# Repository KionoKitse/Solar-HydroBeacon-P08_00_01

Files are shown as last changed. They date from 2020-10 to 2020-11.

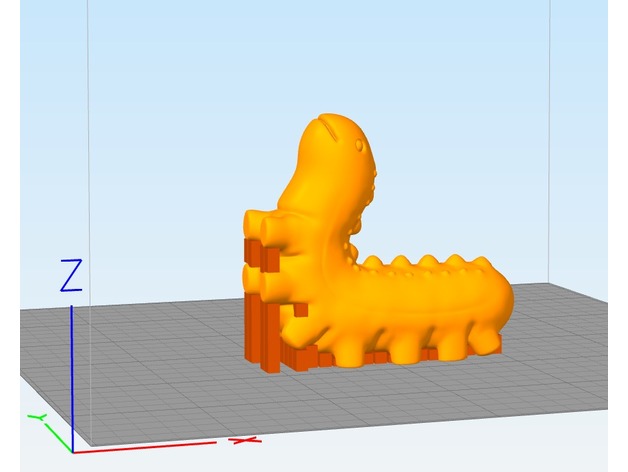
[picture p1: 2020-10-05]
P08_01_00 Thingverse CAD/cute_caterpillar/images/ec77e9b82f7213b1b38d7afa50246b58_preview_featured.jpg

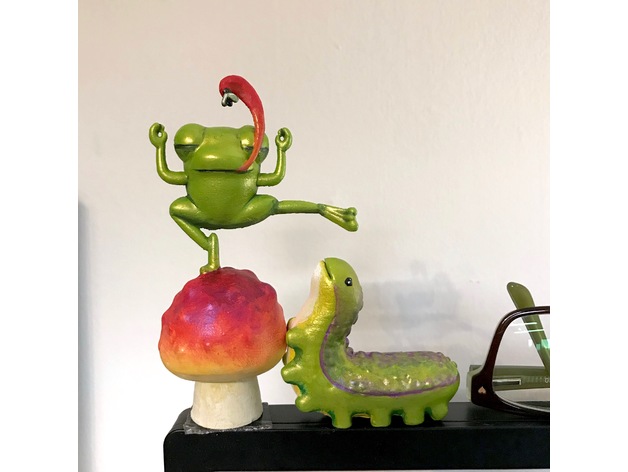
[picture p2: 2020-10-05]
P08_01_00 Thingverse CAD/cute_caterpillar/images/cc7cc02f7ef95b9d1e0543dbf46717a2_preview_featured.jpeg

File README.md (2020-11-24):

### Description  
P08_01_00 Solar HydroBeacon
A solar powered soil moisture sensor project.
 * Solar powered
 * LED indicates soil moisture low or acceptable
 * Low to no maintenance
 * Capacitor as power source
 * Analog components 
 * Low cost
 * Interesting and elegant design
 * Small size
### Notes to user
 * Project documented at https://kionokitse.wordpress.com/solar-hydrobeacon/
 * In development
### What's next
 * Determine typical soil moisture levels
 * Determine trimpot value that would be the best for the typical soil moistures
 * Find voltage supervisors that would work
 * Order solar panels
 * Test led drivers
### Notebook
 * Online circuit simulator [link](http://falstad.com/circuit/)
 * Case design options
	* Case option: [Neko Submarine](https://www.thingiverse.com/thing:3081218) 
	* Case option: [cute caterpillar](https://www.thingiverse.com/thing:3598906)
	* Case option: [Pom Pom Purin keychain](https://www.thingiverse.com/thing:1188272)
 * Voltage detector 
	* Trimpot should be about 50% less than sensor resistance
	* Voltage divider total resistance should be high to limit current flow
	* On build I need to re-tune the circuit
	* Added a 500Ohm resistor to cut down on the wasted current to turn on the green led
 * Solar LED driver
	* Good intro to the solar LED driver featuring the YX8018 IC [Link](https://ez.analog.com/adieducation/university-program/b/blogs/posts/hacking-an-led-solar-garden-light)
	* Solar powered soil moisture sensor project [Link](https://learn.sparkfun.com/tutorials/soil-moisture-sensing-by-hacking-a-solar-light/all)
	* When the CE pin on ANA608 is high the LED will turn ON
	* When the CE pin on ANA608 is low the LED will trun OFF
 * Blink circuit [Link](http://tinyurl.com/y29udzjd)
	* Need to tune the circuit for low voltage operation
	* Increasing the green capacitor size will increase the time that the green capacitor is on
	* Reducing the resistance before the red LED will increase the red led brightness
	* Latest progress on this [Link](http://tinyurl.com/y2kkg7hm)
 * Simulate Solar engines
	* [The Zener-based solar engine](http://solarbotics.net/library/circuits/se_t1_zener.html) [Simulation](https://tinyurl.com/y29gntqv) (not working yet)
	* [FLED-based solar engines](http://solarbotics.net/library/circuits/se_t1_fled.html) [Simulation](https://tinyurl.com/y26xv6wr) (not working yet)
 * Simple blink circuit [Link](https://electronics.stackexchange.com/questions/356947/intuitive-and-iterative-approach-to-understanding-of-blinking-led-circuit)
 * DC-DC converter based on solar LED light
	* Dollar Store Garden Lights As ATtiny Power Supplies [Link](https://hackaday.io/project/164682-a-cheap-and-dangerous-garden-light-boost-converter/details)
		* Interesting use of an ATtiny85V to directly control YX8051 by manipulating the solar voltage input. A cap will hold off the 10V voltage spikes.
	* DC-DC converter based on solar LED light [Link](https://skootsone.yolasite.com/solar-led-msp430.php)
		* Seems to be a more stable version but requires a lot of additional components
	* Running a transmitter and a ATtiny85 off a solar led driver [Link](https://web.archive.org/web/20170119175434/http://www.dolenle.com/proj4.html)
		*No images and it is long but I think it will be worth a replica
	* Using a YX805A to get a stable 5V power output for ATtiny85 or others [Link](https://dzrmo.wordpress.com/2017/01/02/garden-light-redux-aka-joule-thief-p-1/)
	* XY8018 boost regulator with trimpot control [Link](http://www.radioradar.net/radiofan/lighting/yx8018.html) [Translated](https://translate.google.com/translate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)
 * Resources
	* Circuit diagrams making use of LED divers [Link](https://skootsone.yolasite.com/solar-led.php)
		* Interesting design for a blinker I might test
		* Interesting component breakdown of what is inside of a solar led driver

 * Website with some solar circuits maybe useful later [Link](https://www.electroschematics.com/category/solar-projects/)
	
### Progress log 
 * 2020-09-19 Got some garden lights from the store to test these led drivers
 * 2020-09-19 Testing the led drivers. It doesn't look like I can drive an ATtiny85 directly off the boosted voltage
 * 2020-09-19 Fried both led divers. Not sure how but maybe too much heat from the soldering iron
 * 2020-09-21 Officially start project and create Git repository
 * 2020-09-21 Looking for possible designs
 * 2020-09-22 Looking for a analog method to compare voltages
 * 2020-09-23 Created a circuit that turns on a green LED if the resistance is low [link](http://tinyurl.com/y6nuq4zt) 
 * 2020-09-23 Created a circuit design that turns on a red led if the resistance is high [link](http://tinyurl.com/yysaw5k8) 
 * 2020-09-23 Attempted circuit design with both options (not working) [link](http://tinyurl.com/y6hwgj95)
 * 2020-09-24 Looking into logic diagrams
 * 2020-09-24 Got 50 more led divers in the mail
 * 2020-09-25 Created a working simulated circuit at 5v that will turn a red led on if resistance is high or a green led if resistance is low [link](http://tinyurl.com/yyqalqkw)
 * 2020-09-30 Modifying the caterpillar STL for the project
 * 2020-10-01 Searching for a voltage supervisor IC to control when to activate the circuit
 * 2020-10-05 Fined turning the voltage detector circuit for 2V [link](http://tinyurl.com/yxfx4we7)
 * 2020-10-05 Testing sample miller style circuit [Link](http://tinyurl.com/y38uw3cg)
 * 2020-10-05 Improving voltage flow [Link] (http://tinyurl.com/yymy2248)
 * 2020-10-05 Circuit with voltage comparator and solar engine (not really working) [Link](http://tinyurl.com/y5qvovyz)
 * 2020-10-05 Current progress with circuit design [Link](http://tinyurl.com/yxzwtum5)
 * 2020-10-08 Experimenting with the ANA608 solar LED driver
 * 2020-10-08 ANA608 seems to work but I should explore expanded usage scenarios 
 * 2020-10-10 Tested running ATtiny85 directly off ANA608 no luck
 * 2020-10-13 Simple blink circuit from [here](https://www.build-electronic-circuits.com/blinking-led-circuit/)[Link](http://tinyurl.com/y29udzjd)
 * 2020-10-14 Doing research on solar led divers and modifying them for constant boosted DC voltage
 * 2020-10-14 Buy some test parts from mouser
 * 2020-10-15 building test circuits no luck I think mc4742 is an invalid part number
 * 2020-10-17 Tested running ATtiny85 directly off ANA608 no luck
 * 2020-10-26 Mouser parts arrived (2 weeks delivery) 
 * 2020-10-30 Testing [this](https://dzrmo.wordpress.com/2017/01/02/garden-light-redux-aka-joule-thief-p-1/) circuit with the new parts. Seems to work
 * 2020-11-03 Solar power circuit seems to work best with a Schottky diode instead of rectifier diode
 * 2020-11-03 Rectifier diode drops the voltage too low to run green LEDs
 * 2020-11-08 Testing solar power circuit to optimize setup
 * 2020-11-08 Getting stable power from ANA608 stays at about 3.3V when ATtiny85 is doing nothing
 * 2020-11-08 Write initial main AVR sketch
 * 2020-11-08 Created breadboard prototype with moisture sensor, trimpot reference, Green/Red LEDs and microcontroller results successful
 * 2020-11-09 Got the ANA608 with the LDR to work and power the ATtiny85
 * 2020-11-09 LDR helps a lot to delay the start time
 * 2020-11-09 Microcontroller does not reboot when light turned back on only if remove battery
 * 2020-11-09 Smallest capacitor that seems to work okay is 47uF
 * 2020-11-10 Checking space in caterpillar model for battery
 * 2020-11-10 Both batteries seem to fit
 * 2020-11-10 Modifying CAD to make room for LDR
 * 2020-11-16 Needed to use blender to modify CAD
 * 2020-11-16 Printing caterpillar
 * 2020-11-17 Testing new solar panels results are disappointing needs review

### Next Blog Post

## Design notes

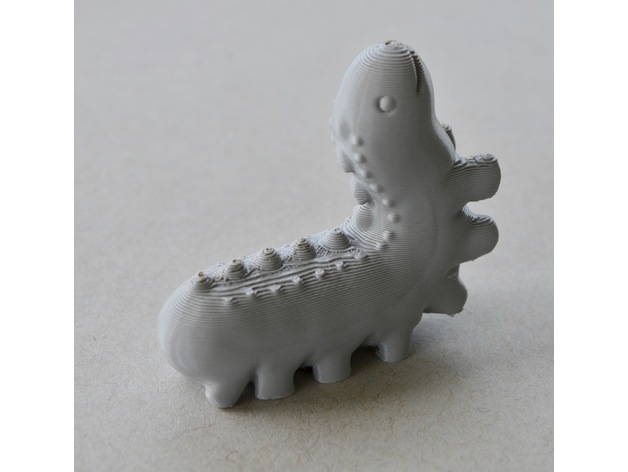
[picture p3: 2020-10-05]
P08_01_00 Thingverse CAD/cute_caterpillar/images/f7e0081296a51953a6b59a4de3f70e1f_preview_featured.jpeg

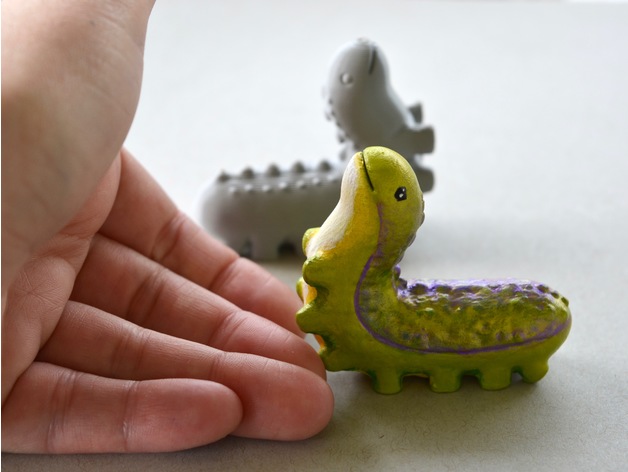
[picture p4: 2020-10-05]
P08_01_00 Thingverse CAD/cute_caterpillar/images/7b63a44b5848a8bd771d972aaded3b9b_preview_featured.jpeg

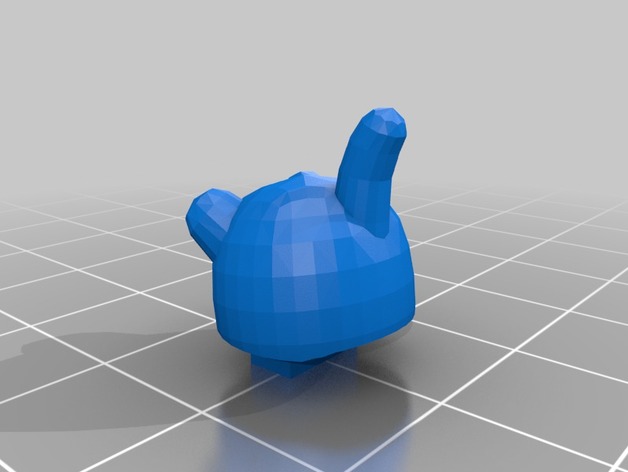
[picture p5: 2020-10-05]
P08_01_00 Thingverse CAD/Neko_Submarine/images/8ecf5cf895d3a4468f53bc3277c36801_preview_featured.jpg

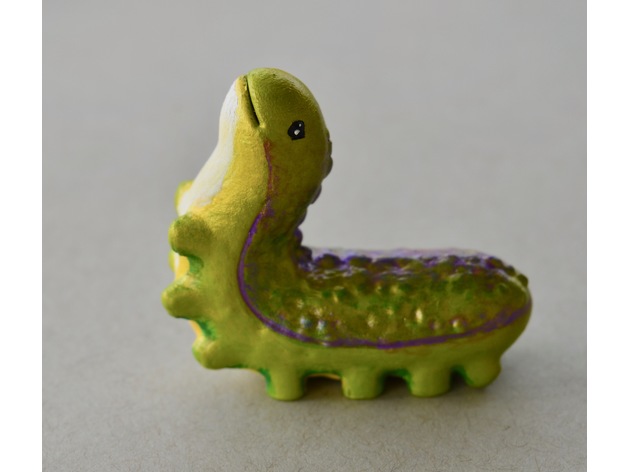
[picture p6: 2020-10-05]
P08_01_00 Thingverse CAD/cute_caterpillar/images/7d05ed157128572da64a1c4cd77189d9_preview_featured.jpeg

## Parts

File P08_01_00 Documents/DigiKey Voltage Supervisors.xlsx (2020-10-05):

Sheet: Filtered
Mfr Part # | Price | Type | Output | Reset | Reset Timeout | Voltage - Threshold | V-On | uA | Notes
BU4315FVE-TR | 0.34206 | Simple Reset/Power-On Reset | Push-Pull, Totem Pole | Active Low | Adjustable/Selectable | 1.5V | 0.7 | 0.55
RT9819C-13GU3 | 0.62 | Simple Reset/Power-On Reset | Push-Pull, Totem Pole | Active Low | 143ms Minimum | 1.3V | 0 | 0 | Invalid
BD5215G-2MTR | 0.67 | Voltage Detector | Open Drain or Open Collector | Active Low | - | 1.5V | 0.8 | 0.27
BU4813G-TR | 0.67 | Simple Reset/Power-On Reset | Open Drain or Open Collector | Active High/Active Low | - | 1.3V | 0.7 | 0.55
XC6120N152NR-G | 0.7 | Voltage Detector | Open Drain or Open Collector | Active Low | - | 1.5V
RN5VD15AA-TR-FE | 0.73 | Voltage Detector | Open Drain or Open Collector | - | - | 1.5V
BU4213G-TR | 0.74 | Simple Reset/Power-On Reset | Open Drain or Open Collector | Active Low | Adjustable/Selectable | 1.3V | 0.7 | 0.55
BU4215G-TR | 0.74 | Simple Reset/Power-On Reset | Open Drain or Open Collector | Active Low | Adjustable/Selectable | 1.5V | 0.7 | 0.55
NCP302LSN15T1G | 0.8 | Simple Reset/Power-On Reset | Push-Pull, Totem Pole | Active Low | Adjustable/Selectable | 1.5V | 0.65 | 0.2
NCP303LSN13T1G | 0.8 | Simple Reset/Power-On Reset | Open Drain or Open Collector | Active Low | Adjustable/Selectable | 1.3V | 0.65 | 0.2
NCP303LSN14T1G | 0.8 | Simple Reset/Power-On Reset | Open Drain or Open Collector | Active Low | Adjustable/Selectable | 1.4V | 0.65 | 0.2
NCP303LSN15T1G | 0.8 | Simple Reset/Power-On Reset | Open Drain or Open Collector | Active Low | Adjustable/Selectable | 1.5V | 0.65 | 0.2
NCP305LSQ15T1G | 0.8 | Simple Reset/Power-On Reset | Open Drain or Open Collector | Active Low | - | 1.5V | 0.65 | 0.2
TC54VC1402ECB713 | 0.8 | Simple Reset/Power-On Reset | Push-Pull, Totem Pole | Active Low | - | 1.4V
TC54VN1402ECB713 | 0.8 | Simple Reset/Power-On Reset | Open Drain or Open Collector | Active Low | - | 1.4V
XC61CN1502MR-G | 0.89 | Voltage Detector | Open Drain or Open Collector | - | - | 1.5V
R3112N131A-TR-FE | 0.92 | Voltage Detector | Open Drain or Open Collector | Active Low | - | 1.3V | 0.7 | 0.5
R3112Q131A-TR-FE | 0.92 | Voltage Detector | Open Drain or Open Collector | Active Low | - | 1.3V
BU4213FVE-TR | 0.95 | Simple Reset/Power-On Reset | Open Drain or Open Collector | Active Low | Adjustable/Selectable | 1.3V | 0.7 | 0.55
R3112D151A-TR-FE | 0.97 | Voltage Detector | Open Drain or Open Collector | Active Low | - | 1.5V | 0.65 | 0.2
R3116Q151C-TR-FE | 1.09 | Voltage Detector | Push-Pull, Totem Pole | Active Low | 85ms Minimum | 1.5V
S-1000C15-I4T1U | 1.14 | Voltage Detector | Push-Pull, Totem Pole | Active Low | - | 1.5V
S-1000N15-I4T1U | 1.14 | Voltage Detector | Open Drain or Open Collector | Active Low | - | 1.5V
S-1000N15-M5T1U | 1.14 | Voltage Detector | Open Drain or Open Collector | Active Low | - | 1.5V
S-80814CLNB-B7ST2U | 1.14 | Voltage Detector | Push-Pull, Totem Pole | Active Low | - | 1.4V
S-80814CLPF-B7STFU | 1.14 | Voltage Detector | Push-Pull, Totem Pole | Active Low | - | 1.4V
S-80814CNNB-B9ST2U | 1.14 | Voltage Detector | Open Drain or Open Collector | Active Low | - | 1.4V
S-80815CLNB-B6AT2U | 1.14 | Voltage Detector | Push-Pull, Totem Pole | Active Low | - | 1.5V
S-80815CLPF-B6ATFU | 1.14 | Voltage Detector | Push-Pull, Totem Pole | Active Low | - | 1.5V
S-80815CNMC-B8AT2U | 1.14 | Voltage Detector | Open Drain or Open Collector | Active Low | - | 1.5V
S-80815CNNB-B8AT2U | 1.14 | Voltage Detector | Open Drain or Open Collector | Active Low | - | 1.5V
R3116K151A-TR | 1.15 | Voltage Detector | Open Drain or Open Collector | Active Low | 85ms Minimum | 1.5V
R3116K151C-TR | 1.15 | Voltage Detector | Push-Pull, Totem Pole | Active Low | 85ms Minimum | 1.5V
S-1009C13I-N4T1U | 1.18 | Voltage Detector | Push-Pull, Totem Pole | Active Low | - | 1.3V
S-1009C14I-M5T1U | 1.18 | Voltage Detector | Push-Pull, Totem Pole | Active Low | - | 1.4V
S-1009C15I-I4T1U | 1.18 | Voltage Detector | Push-Pull, Totem Pole | Active Low | - | 1.5V
S-1009N13I-I4T1U | 1.18 | Voltage Detector | Open Drain or Open Collector | Active Low | - | 1.3V
S-1009N13I-M5T1U | 1.18 | Voltage Detector | Open Drain or Open Collector | Active Low | - | 1.3V
S-1009N14I-M5T1U | 1.18 | Voltage Detector | Open Drain or Open Collector | Active Low | - | 1.4V
S-1009N15I-I4T1U | 1.18 | Voltage Detector | Open Drain or Open Collector | Active Low | - | 1.5V
S-1009N15I-M5T1U | 1.18 | Voltage Detector | Open Drain or Open Collector | Active Low | - | 1.5V
S-1009N15I-N4T1U | 1.18 | Voltage Detector | Open Drain or Open Collector | Active Low | - | 1.5V
S-80913CNMC-G8HT2U | 1.18 | Voltage Detector | Open Drain or Open Collector | Active Low | 2.7ms Minimum | 1.3V
S-80914CLMC-G6JT2U | 1.18 | Voltage Detector | Push-Pull, Totem Pole | Active Low | 2.7ms Minimum | 1.4V
S-80914CLPF-G6JTFU | 1.18 | Voltage Detector | Push-Pull, Totem Pole | Active Low | 2.7ms Minimum | 1.4V
S-80914CNPF-G8JTFU | 1.18 | Voltage Detector | Open Drain or Open Collector | Active Low | 2.7ms Minimum | 1.4V
S-80915CLMC-G6KT2U | 1.18 | Voltage Detector | Push-Pull, Totem Pole | Active Low | 18ms Minimum | 1.5V
S-80915CLNB-G6KT2U | 1.18 | Voltage Detector | Push-Pull, Totem Pole | Active Low | 18ms Minimum | 1.5V
S-80915CLPF-G6KTFU | 1.18 | Voltage Detector | Push-Pull, Totem Pole | Active Low | 18ms Minimum | 1.5V
S-80915CNMC-G8KT2U | 1.18 | Voltage Detector | Open Drain or Open Collector | Active Low | 20ms Minimum | 1.5V
S-80915CNPF-G8KTFU | 1.18 | Voltage Detector | Open Drain or Open Collector | Active Low | 20ms Minimum | 1.5V
S-1002CA15I-M5T1U | 1.3 | Voltage Detector | Push-Pull, Totem Pole | Active Low | - | 1.5V
R3118N151A-TR-FE | 1.32 | Voltage Detector | Open Drain or Open Collector | Active Low | 70ms Minimum | 1.5V
R3118N151C-TR-FE | 1.32 | Voltage Detector | Push-Pull, Totem Pole | Active Low | 70ms Minimum | 1.5V
S-1004CA14I-I6T1U | 1.35 | Voltage Detector | Push-Pull, Totem Pole | Active Low | - | 1.4V
S-1004CA15I-M5T1U | 1.35 | Voltage Detector | Push-Pull, Totem Pole | Active Low | - | 1.5V
S-1004NB15I-M5T1U | 1.35 | Voltage Detector | Open Drain or Open Collector | Active Low | - | 1.5V
TPS3803G15DCKR | 1.35 | Simple Reset/Power-On Reset | Open Drain or Open Collector | Active Low | 5µs Typical Propagation Delay | 1.4V
TPS3808G15DBVR | 2.38 | Simple Reset/Power-On Reset | Open Drain or Open Collector | Active Low | Adjustable/Selectable | 1.4V
TPS389015DSER | 2.42 | Simple Reset/Power-On Reset | Open Drain or Open Collector | Active Low | - | 1.5V
TPS3808G15DBVT | 2.44 | Simple Reset/Power-On Reset | Open Drain or Open Collector | Active Low | Adjustable/Selectable | 1.4V
TPS389015DSET | 2.48 | Simple Reset/Power-On Reset | Open Drain or Open Collector | Active Low | - | 1.5V
TPS3808G15DRVT | 2.54 | Simple Reset/Power-On Reset | Open Drain or Open Collector | Active Low | Adjustable/Selectable | 1.4V

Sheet: Full Results
Voltage - Threshold | Mfr Part # | Price | Type | Output | Reset | Reset Timeout
1.5V | BU4315FVE-TR | 0.34206 | Simple Reset/Power-On Reset | Push-Pull, Totem Pole | Active Low | Adjustable/Selectable
1.3V | RT9819C-13GU3 | 0.62 | Simple Reset/Power-On Reset | Push-Pull, Totem Pole | Active Low | 143ms Minimum
1.5V | BD5215G-2MTR | 0.67 | Voltage Detector | Open Drain or Open Collector | Active Low | -
1.2V | BD5212G-2MTR | 0.67 | Voltage Detector | Open Drain or Open Collector | Active Low | -
1V | BD5210G-2MTR | 0.67 | Voltage Detector | Open Drain or Open Collector | Active Low | -
1V | BU4810G-TR | 0.67 | Simple Reset/Power-On Reset | Open Drain or Open Collector | Active High/Active Low | -
1.3V | BU4813G-TR | 0.67 | Simple Reset/Power-On Reset | Open Drain or Open Collector | Active High/Active Low | -
0.9V | BU4809G-TR | 0.67 | Simple Reset/Power-On Reset | Open Drain or Open Collector | Active High/Active Low | -
1.5V | XC6120N152NR-G | 0.7 | Voltage Detector | Open Drain or Open Collector | Active Low | -
0.9V | NCP301LSN09T1G | 0.71 | Simple Reset/Power-On Reset | Open Drain or Open Collector | Active Low | -
0.9V | NCP303LSN09T2G | 0.71 | Simple Reset/Power-On Reset | Open Drain or Open Collector | Active Low | Adjustable/Selectable
1.5V | RN5VD15AA-TR-FE | 0.73 | Voltage Detector | Open Drain or Open Collector | - | -
0.9V | RN5VD09AA-TR-FE | 0.73 | Voltage Detector | Open Drain or Open Collector | - | -
1.5V | BU4215G-TR | 0.74 | Simple Reset/Power-On Reset | Open Drain or Open Collector | Active Low | Adjustable/Selectable
0.9V | BU4209G-TR | 0.74 | Simple Reset/Power-On Reset | Open Drain or Open Collector | Active Low | Adjustable/Selectable
1V | BU4210G-TR | 0.74 | Simple Reset/Power-On Reset | Open Drain or Open Collector | Active Low | Adjustable/Selectable
1.3V | BU4213G-TR | 0.74 | Simple Reset/Power-On Reset | Open Drain or Open Collector | Active Low | Adjustable/Selectable
1.2V | BU4212G-TR | 0.74 | Simple Reset/Power-On Reset | Open Drain or Open Collector | Active Low | Adjustable/Selectable
1.1V | BU4211G-TR | 0.74 | Simple Reset/Power-On Reset | Open Drain or Open Collector | Active Low | Adjustable/Selectable
1.1V | XC6120C112HR-G | 0.79 | Voltage Detector | Push-Pull, Totem Pole | Active Low | -
1V | NCP303LSN10T1G | 0.8 | Simple Reset/Power-On Reset | Open Drain or Open Collector | Active Low | Adjustable/Selectable
1.1V | NCP303LSN11T1G | 0.8 | Simple Reset/Power-On Reset | Open Drain or Open Collector | Active Low | Adjustable/Selectable
1.5V | NCP302LSN15T1G | 0.8 | Simple Reset/Power-On Reset | Push-Pull, Totem Pole | Active Low | Adjustable/Selectable
0.9V | NCP305LSQ09T1G | 0.8 | Simple Reset/Power-On Reset | Push-Pull, Totem Pole | Active Low | -
1.3V | NCP303LSN13T1G | 0.8 | Simple Reset/Power-On Reset | Open Drain or Open Collector | Active Low | Adjustable/Selectable
1.4V | NCP303LSN14T1G | 0.8 | Simple Reset/Power-On Reset | Open Drain or Open Collector | Active Low | Adjustable/Selectable
0.9V | NCP302LSN09T1G | 0.8 | Simple Reset/Power-On Reset | Push-Pull, Totem Pole | Active Low | Adjustable/Selectable
0.9V | NCP302HSN09T1G | 0.8 | Simple Reset/Power-On Reset | Push-Pull, Totem Pole | Active High | Adjustable/Selectable
1.2V | NCP301LSN12T1G | 0.8 | Simple Reset/Power-On Reset | Open Drain or Open Collector | Active Low | -
0.9V | NCP301HSN09T1G | 0.8 | Simple Reset/Power-On Reset | Open Drain or Open Collector | Active High | -
1.4V | TC54VN1402ECB713 | 0.8 | Simple Reset/Power-On Reset | Open Drain or Open Collector | Active Low | -
1.5V | NCP303LSN15T1G | 0.8 | Simple Reset/Power-On Reset | Open Drain or Open Collector | Active Low | Adjustable/Selectable
0.9V | NCP300HSN09T1G | 0.8 | Simple Reset/Power-On Reset | Push-Pull, Totem Pole | Active High | -
1.1V | NCP305LSQ11T1G | 0.8 | Simple Reset/Power-On Reset | Open Drain or Open Collector | Active Low | -
0.9V | NCP300LSN09T1G | 0.8 | Simple Reset/Power-On Reset | Push-Pull, Totem Pole | Active Low | -
1.5V | NCP305LSQ15T1G | 0.8 | Simple Reset/Power-On Reset | Open Drain or Open Collector | Active Low | -
1.4V | TC54VC1402ECB713 | 0.8 | Simple Reset/Power-On Reset | Push-Pull, Totem Pole | Active Low | -
1V | BU4810F-TR | 0.83 | Simple Reset/Power-On Reset | Open Drain or Open Collector | Active High/Active Low | -
1.2V | NCP803SN120T1G | 0.83 | Simple Reset/Power-On Reset | Open Drain or Open Collector | Active Low | 140ms Minimum
1.2V | MAX809SQ120T1G | 0.88 | Simple Reset/Power-On Reset | Push-Pull, Totem Pole | Active Low | 140ms Minimum
1.2V | MAX810SN120T1G | 0.88 | Simple Reset/Power-On Reset | Push-Pull, Totem Pole | Active High | 140ms Minimum
1.2V | MAX809SN120T1G | 0.88 | Simple Reset/Power-On Reset | Push-Pull, Totem Pole | Active Low | 140ms Minimum
1.2V | MAX803SQ120T1G | 0.88 | Simple Reset/Power-On Reset | Open Drain or Open Collector | Active Low | 140ms Minimum
1.5V | XC61CN1502MR-G | 0.89 | Voltage Detector | Open Drain or Open Collector | - | -
1.3V | R3112N131A-TR-FE | 0.92 | Voltage Detector | Open Drain or Open Collector | Active Low | -
1.2V | R3112N121A-TR-FE | 0.92 | Voltage Detector | Open Drain or Open Collector | Active Low | -
1.2V | R3112N121C-TR-FE | 0.92 | Voltage Detector | Push-Pull, Totem Pole | Active Low | -
0.9V | R3112N091A-TR-FE | 0.92 | Voltage Detector | Open Drain or Open Collector | Active Low | -
1.3V | R3112Q131A-TR-FE | 0.92 | Voltage Detector | Open Drain or Open Collector | Active Low | -
1.2V | R3111N122A-TR-FE | 0.92 | Voltage Detector | Open Drain or Open Collector | Active Low | 100µs Maximum
0.9V | R3111Q091A-TR-FE | 0.92 | Voltage Detector | Open Drain or Open Collector | Active Low | 100µs Maximum
1V | BU4210FVE-TR | 0.95 | Simple Reset/Power-On Reset | Open Drain or Open Collector | Active Low | Adjustable/Selectable
1.3V | BU4213FVE-TR | 0.95 | Simple Reset/Power-On Reset | Open Drain or Open Collector | Active Low | Adjustable/Selectable
0.9V | BU4209FVE-TR | 0.95 | Simple Reset/Power-On Reset | Open Drain or Open Collector | Active Low | Adjustable/Selectable
1.2V | BU4212FVE-TR | 0.95 | Simple Reset/Power-On Reset | Open Drain or Open Collector | Active Low | Adjustable/Selectable
0.9V | R3112D091A-TR-FE | 0.97 | Voltage Detector | Open Drain or Open Collector | Active Low | -
1.5V | R3112D151A-TR-FE | 0.97 | Voltage Detector | Open Drain or Open Collector | Active Low | -
1V | BU4210F-TR | 0.97 | Simple Reset/Power-On Reset | Open Drain or Open Collector | Active Low | Adjustable/Selectable
0.9V | BU4209F-TR | 0.97 | Simple Reset/Power-On Reset | Open Drain or Open Collector | Active Low | Adjustable/Selectable
1.1V | BU4211F-TR | 0.97 | Simple Reset/Power-On Reset | Open Drain or Open Collector | Active Low | Adjustable/Selectable
1.2V | BU4212F-TR | 0.97 | Simple Reset/Power-On Reset | Open Drain or Open Collector | Active Low | Adjustable/Selectable
1.1V | TPS3839G12DBZR | 1.05 | Simple Reset/Power-On Reset | Push-Pull, Totem Pole | Active Low | 120ms Minimum
1V | R3116N101C-TR-FE | 1.09 | Voltage Detector | Push-Pull, Totem Pole | - | 80ms Minimum
1.5V | R3116Q151C-TR-FE | 1.09 | Voltage Detector | Push-Pull, Totem Pole | Active Low | 85ms Minimum
0.8V | R3116Q081A-TR-FE | 1.09 | Voltage Detector | Open Drain or Open Collector | Active Low | 80ms Minimum
1.5V | S-80815CLPF-B6ATFU | 1.14 | Voltage Detector | Push-Pull, Totem Pole | Active Low | -
1.5V | S-80815CNNB-B8AT2U | 1.14 | Voltage Detector | Open Drain or Open Collector | Active Low | -
1.5V | S-1000N15-I4T1U | 1.14 | Voltage Detector | Open Drain or Open Collector | Active Low | -
1.5V | S-80815CLNB-B6AT2U | 1.14 | Voltage Detector | Push-Pull, Totem Pole | Active Low | -
0.9V | S-80809CLNB-B7NT2U | 1.14 | Voltage Detector | Push-Pull, Totem Pole | Active Low | -
0.8V | S-80808CLNB-B7MT2U | 1.14 | Voltage Detector | Push-Pull, Totem Pole | Active Low | -
1.4V | S-80814CNNB-B9ST2U | 1.14 | Voltage Detector | Open Drain or Open Collector | Active Low | -
1.4V | S-80814CLNB-B7ST2U | 1.14 | Voltage Detector | Push-Pull, Totem Pole | Active Low | -
1.5V | S-80815CNMC-B8AT2U | 1.14 | Voltage Detector | Open Drain or Open Collector | Active Low | -
1.5V | S-1000N15-M5T1U | 1.14 | Voltage Detector | Open Drain or Open Collector | Active Low | -
0.9V | S-80809CNNB-B9NT2U | 1.14 | Voltage Detector | Open Drain or Open Collector | Active Low | -
1V | S-80810CNNB-B9OT2U | 1.14 | Voltage Detector | Open Drain or Open Collector | Active Low | -
1V | S-80810CNPF-B9OTFU | 1.14 | Voltage Detector | Open Drain or Open Collector | Active Low | -
1.4V | S-80814CLPF-B7STFU | 1.14 | Voltage Detector | Push-Pull, Totem Pole | Active Low | -
1.2V | S-80812CNNB-B9QT2U | 1.14 | Voltage Detector | Open Drain or Open Collector | Active Low | -
0.9V | S-80809CNPF-B9NTFU | 1.14 | Voltage Detector | Open Drain or Open Collector | Active Low | -
1.1V | S-80811CNPF-B9PTFU | 1.14 | Voltage Detector | Open Drain or Open Collector | Active Low | -
1.5V | S-1000C15-I4T1U | 1.14 | Voltage Detector | Push-Pull, Totem Pole | Active Low | -
0.8V | S-80808CNNB-B9MT2U | 1.14 | Voltage Detector | Open Drain or Open Collector | Active Low | -
1V | R3116K101C-TR | 1.15 | Voltage Detector | Push-Pull, Totem Pole | Active Low | 80ms Minimum
1.5V | R3116K151C-TR | 1.15 | Voltage Detector | Push-Pull, Totem Pole | Active Low | 85ms Minimum
1.5V | R3116K151A-TR | 1.15 | Voltage Detector | Open Drain or Open Collector | Active Low | 85ms Minimum
1.2V | S-1009C12I-N4T1U | 1.18 | Voltage Detector | Push-Pull, Totem Pole | Active Low | -
1.1V | S-1009N11I-N4T1U | 1.18 | Voltage Detector | Open Drain or Open Collector | Active Low | -
1.5V | S-80915CLPF-G6KTFU | 1.18 | Voltage Detector | Push-Pull, Totem Pole | Active Low | 18ms Minimum
1.5V | S-1009N15I-M5T1U | 1.18 | Voltage Detector | Open Drain or Open Collector | Active Low | -
1.5V | S-80915CLNB-G6KT2U | 1.18 | Voltage Detector | Push-Pull, Totem Pole | Active Low | 18ms Minimum
1.5V | S-80915CNMC-G8KT2U | 1.18 | Voltage Detector | Open Drain or Open Collector | Active Low | 20ms Minimum
1.2V | S-1009N12I-I4T1U | 1.18 | Voltage Detector | Open Drain or Open Collector | Active Low | -
0.8V | S-1009C08I-N4T1U | 1.18 | Voltage Detector | Push-Pull, Totem Pole | Active Low | -
1.4V | S-1009C14I-M5T1U | 1.18 | Voltage Detector | Push-Pull, Totem Pole | Active Low | -
1.3V | S-1009C13I-N4T1U | 1.18 | Voltage Detector | Push-Pull, Totem Pole | Active Low | -
1.4V | S-80914CLMC-G6JT2U | 1.18 | Voltage Detector | Push-Pull, Totem Pole | Active Low | 2.7ms Minimum
1V | S-1009C10I-I4T1U | 1.18 | Voltage Detector | Push-Pull, Totem Pole | Active Low | -
1V | S-1009N10I-M5T1U | 1.18 | Voltage Detector | Open Drain or Open Collector | Active Low | -
1V | S-1009N10I-N4T1U | 1.18 | Voltage Detector | Open Drain or Open Collector | Active Low | -
1.2V | S-1009N12I-M5T1U | 1.18 | Voltage Detector | Open Drain or Open Collector | Active Low | -
1.2V | S-1009C12I-M5T1U | 1.18 | Voltage Detector | Push-Pull, Totem Pole | Active Low | -
1.5V | S-1009C15I-I4T1U | 1.18 | Voltage Detector | Push-Pull, Totem Pole | Active Low | -
0.8V | S-1009N08I-N4T1U | 1.18 | Voltage Detector | Open Drain or Open Collector | Active Low | -
0.9V | S-1009N09I-N4T1U | 1.18 | Voltage Detector | Open Drain or Open Collector | Active Low | -
1.5V | S-80915CLMC-G6KT2U | 1.18 | Voltage Detector | Push-Pull, Totem Pole | Active Low | 18ms Minimum
1.5V | S-1009N15I-N4T1U | 1.18 | Voltage Detector | Open Drain or Open Collector | Active Low | -
0.9V | S-1009N09I-M5T1U | 1.18 | Voltage Detector | Open Drain or Open Collector | Active Low | -
1.3V | S-1009N13I-M5T1U | 1.18 | Voltage Detector | Open Drain or Open Collector | Active Low | -
1V | S-1009C10I-N4T1U | 1.18 | Voltage Detector | Push-Pull, Totem Pole | Active Low | -
1.4V | S-1009N14I-M5T1U | 1.18 | Voltage Detector | Open Drain or Open Collector | Active Low | -
1.4V | S-80914CNPF-G8JTFU | 1.18 | Voltage Detector | Open Drain or Open Collector | Active Low | 2.7ms Minimum
1.3V | S-80913CNMC-G8HT2U | 1.18 | Voltage Detector | Open Drain or Open Collector | Active Low | 2.7ms Minimum
1.3V | S-1009N13I-I4T1U | 1.18 | Voltage Detector | Open Drain or Open Collector | Active Low | -
0.8V | S-1009N08I-I4T1U | 1.18 | Voltage Detector | Open Drain or Open Collector | Active Low | -
1.1V | S-1009N11I-M5T1U | 1.18 | Voltage Detector | Open Drain or Open Collector | Active Low | -
1.4V | S-80914CLPF-G6JTFU | 1.18 | Voltage Detector | Push-Pull, Totem Pole | Active Low | 2.7ms Minimum
1.5V | S-80915CNPF-G8KTFU | 1.18 | Voltage Detector | Open Drain or Open Collector | Active Low | 20ms Minimum
1.5V | S-1009N15I-I4T1U | 1.18 | Voltage Detector | Open Drain or Open Collector | Active Low | -
0.9V | TPS3839A09DBZT | 1.21 | Simple Reset/Power-On Reset | Push-Pull, Totem Pole | Active Low | 120ms Minimum
1.1V | TPS3839G12DBZT | 1.21 | Simple Reset/Power-On Reset | Push-Pull, Totem Pole | Active Low | 120ms Minimum
1V | ADM8642T100ACBZ-R7 | 1.26 | Voltage Detector | Open Drain or Open Collector | - | -
1.5V | S-1002CA15I-M5T1U | 1.3 | Voltage Detector | Push-Pull, Totem Pole | Active Low | -
1V | S-1002CA10I-M5T1U | 1.3 | Voltage Detector | Push-Pull, Totem Pole | Active Low | -
1.2V | S-1002CB12I-N4T1U | 1.3 | Voltage Detector | Push-Pull, Totem Pole | Active Low | -
1V | S-1002NA10I-M5T1U | 1.3 | Voltage Detector | Open Drain or Open Collector | Active Low | -
1.11V, 3.075V | STM6717TGWY6F | 1.3 | Multi-Voltage Supervisor | Open Drain or Open Collector | Active Low | 140ms Minimum
1.05V, 2.925V | STM6717SFWY6F | 1.3 | Multi-Voltage Supervisor | Open Drain or Open Collector | Active Low | 140ms Minimum
1.11V, 3.075V | STM6717TGGWY6F | 1.3 | Multi-Voltage Supervisor | Open Drain or Open Collector | Active Low | 600ms Minimum
1.05V, 2.925V | STM6718SFWY6F | 1.3 | Multi-Voltage Supervisor | Push-Pull, Totem Pole | Active Low | 140ms Minimum
0.788V, 2.925V | STM6717SDWY6F | 1.3 | Multi-Voltage Supervisor | Open Drain or Open Collector | Active Low | 140ms Minimum
1.5V | R3118N151C-TR-FE | 1.32 | Voltage Detector | Push-Pull, Totem Pole | Active Low | 70ms Minimum
0.8V | R3118N081A-TR-FE | 1.32 | Voltage Detector | Open Drain or Open Collector | Active Low | 70ms Minimum
1.5V | R3118N151A-TR-FE | 1.32 | Voltage Detector | Open Drain or Open Collector | Active Low | 70ms Minimum
1V | R3118N101A-TR-FE | 1.32 | Voltage Detector | Open Drain or Open Collector | Active Low | 70ms Minimum
0.8V | R3118Q082A-TR-FE | 1.32 | Voltage Detector | Open Drain or Open Collector | Active Low | 70ms Minimum
1.1V | TPS3839G12DQNT | 1.32 | Simple Reset/Power-On Reset | Push-Pull, Totem Pole | Active Low | 120ms Minimum
0.9V | TPS3839A09DQNT | 1.32 | Simple Reset/Power-On Reset | Push-Pull, Totem Pole | Active Low | 120ms Minimum
0.9V | TPS3831A09DQNR | 1.32 | Simple Reset/Power-On Reset | Push-Pull, Totem Pole | Active Low | 120ms Minimum
1V | S-1004CA10I-I6T1U | 1.35 | Voltage Detector | Push-Pull, Totem Pole | Active Low | -
1V | S-1004NA10I-I6T1U | 1.35 | Voltage Detector | Open Drain or Open Collector | Active Low | -
1.1V | S-1004NA11I-I6T1U | 1.35 | Voltage Detector | Open Drain or Open Collector | Active Low | -
1V | S-1004CA10I-M5T1U | 1.35 | Voltage Detector | Push-Pull, Totem Pole | Active Low | -
1.5V | S-1004NB15I-M5T1U | 1.35 | Voltage Detector | Open Drain or Open Collector | Active Low | -
1V | S-1004NA10I-M5T1U | 1.35 | Voltage Detector | Open Drain or Open Collector | Active Low | -
1.5V | S-1004CA15I-M5T1U | 1.35 | Voltage Detector | Push-Pull, Totem Pole | Active Low | -
1.4V | S-1004CA14I-I6T1U | 1.35 | Voltage Detector | Push-Pull, Totem Pole | Active Low | -
1.2V | S-1004NB12I-M5T1U | 1.35 | Voltage Detector | Open Drain or Open Collector | Active Low | -
1.2V | S-1004NA12I-I6T1U | 1.35 | Voltage Detector | Open Drain or Open Collector | Active Low | -
1.2V | S-1004NA12I-M5T1U | 1.35 | Voltage Detector | Open Drain or Open Collector | Active Low | -
1.11V, 3.075V | STM6718TGWY6F | 1.35 | Multi-Voltage Supervisor | Push-Pull, Totem Pole | Active Low | 140ms Minimum
0.875V, 2.925V | STM6717SJWY6F | 1.35 | Multi-Voltage Supervisor | Open Drain or Open Collector | Active Low | 140ms Minimum
1.11V, 3.075V | STM6778TGWB6F | 1.35 | Multi-Voltage Supervisor | Push-Pull, Totem Pole | Active Low | 140ms Minimum
1.4V | TPS3803G15DCKR | 1.35 | Simple Reset/Power-On Reset | Open Drain or Open Collector | Active Low | 5µs Typical Propagation Delay
1.11V, 3.075V, Adj | STM6719TGWB6F | 1.39 | Multi-Voltage Supervisor | Open Drain or Open Collector | Active Low | 140ms Minimum
1.05V, 2.925V, Adj | STM6719SFWB6F | 1.39 | Multi-Voltage Supervisor | Open Drain or Open Collector | Active Low | 140ms Minimum
1.11V, 3.075V, Adj | STM6720TGWB6F | 1.39 | Multi-Voltage Supervisor | Push-Pull, Totem Pole | Active Low | 140ms Minimum
1.05V, 2.925V, Adj | STM6720SFWB6F | 1.39 | Multi-Voltage Supervisor | Push-Pull, Totem Pole | Active Low | 140ms Minimum
0.4V | MIC2790N-04VD6-T5 | 1.44 | Simple Reset/Power-On Reset | Open Drain or Open Collector | Active Low | Adjustable/Selectable
0.4V | MIC2790N-04VMT-T5 | 1.44 | Simple Reset/Power-On Reset | Open Drain or Open Collector | Active Low | Adjustable/Selectable
1.1V | TPS3831G12DQNT | 1.51 | Simple Reset/Power-On Reset | Push-Pull, Totem Pole | Active Low | 120ms Minimum
0.9V | TPS3831A09DQNT | 1.51 | Simple Reset/Power-On Reset | Push-Pull, Totem Pole | Active Low | 120ms Minimum
1.11V, 3.078V, Adj, Adj | STM6904TGEDS6F | 1.59 | Multi-Voltage Supervisor | Open Drain or Open Collector | Active Low | 140ms Minimum
1.2V | NJU2102AM-TE1 | 1.73 | Watchdog Circuit | - | Active High/Active Low | -
1.11V, 3.078V, Adj, Adj, Adj | STM6905TGEDS6F | 1.76 | Multi-Voltage Supervisor | Open Drain or Open Collector | Active Low | 140ms Minimum
0.4V | MP6400DJ-01-LF-Z | 1.95 | Simple Reset/Power-On Reset | Open Drain or Open Collector | Active Low | Adjustable/Selectable
1.1V | ADM8612N110ACBZ-R7 | 2.11 | Simple Reset/Power-On Reset | Open Drain or Open Collector | Active Low | 200ms Typical
0.4V | MP6400DG-01-LF-Z | 2.11 | Simple Reset/Power-On Reset | Open Drain or Open Collector | Active Low | Adjustable/Selectable
1.1V | TLC7701IDR | 2.26 | Simple Reset/Power-On Reset | Push-Pull, Totem Pole | Active High/Active Low | 1.1ms Minimum
1.313V, 2.925V, Adj | STM6719SHWB6F | 2.27 | Multi-Voltage Supervisor | Open Drain or Open Collector | Active Low | 140ms Minimum
1.11V, 3.075V, Adj | MAX6743XKTGD3+T | 2.27033 | Multi-Voltage Supervisor | Push-Pull, Totem Pole | Active Low | 150ms Minimum
1.12V | TPS3808G12DBVR | 2.38 | Simple Reset/Power-On Reset | Open Drain or Open Collector | Active Low | Adjustable/Selectable
0.84V | TPS3808G09DBVRG4 | 2.38 | Simple Reset/Power-On Reset | Open Drain or Open Collector | Active Low | Adjustable/Selectable
1.16V | TPS3808G125DBVR | 2.38 | Simple Reset/Power-On Reset | Open Drain or Open Collector | Active Low | Adjustable/Selectable
1.12V | TPS3808G12DRVR | 2.38 | Simple Reset/Power-On Reset | Open Drain or Open Collector | Active Low | Adjustable/Selectable
0.84V | TPS3808G09DBVR | 2.38 | Simple Reset/Power-On Reset | Open Drain or Open Collector | Active Low | Adjustable/Selectable
1.4V | TPS3808G15DBVR | 2.38 | Simple Reset/Power-On Reset | Open Drain or Open Collector | Active Low | Adjustable/Selectable
1.2V | TPS389012DSER | 2.42 | Simple Reset/Power-On Reset | Open Drain or Open Collector | Active Low | -
1.5V | TPS389015DSER | 2.42 | Simple Reset/Power-On Reset | Open Drain or Open Collector | Active Low | -
1.12V | TPS3808G12DRVT | 2.44 | Simple Reset/Power-On Reset | Open Drain or Open Collector | Active Low | Adjustable/Selectable
0.84V | TPS3808G09DBVT | 2.44 | Simple Reset/Power-On Reset | Open Drain or Open Collector | Active Low | Adjustable/Selectable
1.16V | TPS3808G125DBVT | 2.44 | Simple Reset/Power-On Reset | Open Drain or Open Collector | Active Low | Adjustable/Selectable
1.4V | TPS3808G15DBVT | 2.44 | Simple Reset/Power-On Reset | Open Drain or Open Collector | Active Low | Adjustable/Selectable
1.12V | TPS3808G12DBVT | 2.44 | Simple Reset/Power-On Reset | Open Drain or Open Collector | Active Low | Adjustable/Selectable
1.1V | TLC7701IPWR | 2.45 | Simple Reset/Power-On Reset | Push-Pull, Totem Pole | Active High/Active Low | 1.1ms Minimum
1.5V | TPS389015DSET | 2.48 | Simple Reset/Power-On Reset | Open Drain or Open Collector | Active Low | -
1.2V | TPS389012DSET | 2.48 | Simple Reset/Power-On Reset | Open Drain or Open Collector | Active Low | -
1.16V | TPS3808G125QDBVRQ1 | 2.5 | Simple Reset/Power-On Reset | Open Drain or Open Collector | Active Low | Adjustable/Selectable
1.12V | TPS3808G12QDBVRQ1 | 2.5 | Simple Reset/Power-On Reset | Open Drain or Open Collector | Active Low | Adjustable/Selectable
0.4V | MP6400DG-01-LF-P | 2.54 | Simple Reset/Power-On Reset | Open Drain or Open Collector | Active Low | Adjustable/Selectable
1.4V | TPS3808G15DRVT | 2.54 | Simple Reset/Power-On Reset | Open Drain or Open Collector | Active Low | Adjustable/Selectable
0.84V | MP6400DG-09-LF-P | 2.54 | Simple Reset/Power-On Reset | Open Drain or Open Collector | Active Low | Adjustable/Selectable
1.12V | MP6400DG-12-LF-P | 2.54 | Simple Reset/Power-On Reset | Open Drain or Open Collector | Active Low | Adjustable/Selectable
1.2V | TPS389012QDSERQ1 | 2.54 | Simple Reset/Power-On Reset | Open Drain or Open Collector | Active Low | -
1.2V | TPS3703A5120DSER | 2.59 | Simple Reset/Power-On Reset | Open Drain or Open Collector | Active Low | 140ms Minimum
0.5V | ADM8615Z050ACBZ-R7 | 2.64 | Simple Reset/Power-On Reset | Open Drain or Open Collector | Active Low | 170ms Minimum
0.8V | TPS3870J4080DSERQ1 | 2.76 | Simple Reset/Power-On Reset | Open Drain or Open Collector | Active Low | 140ms Minimum
0.8V | TPS3703E4080DSERQ1 | 2.76 | Simple Reset/Power-On Reset | Open Drain or Open Collector | Active Low | -
1.1V | TLC7701ID | 2.95 | Simple Reset/Power-On Reset | Push-Pull, Totem Pole | Active High/Active Low | 1.1ms Minimum
1.1V | TLC7701IPW | 2.95 | Simple Reset/Power-On Reset | Push-Pull, Totem Pole | Active High/Active Low | 1.1ms Minimum
0.4V | TPS3850H01DRCR | 2.95 | Simple Reset/Power-On Reset | Open Drain or Open Collector | Active Low | Adjustable/Selectable
1.08V | TPS3125J12DBVR | 3.03 | Simple Reset/Power-On Reset | Push-Pull, Totem Pole | Active High/Active Low | 100ms Minimum
1.2V | TPS3702CX12DDCR | 3.1 | Voltage Detector | Open Drain or Open Collector | Active Low | -
1.25V | TPS3703A7125DSERQ1 | 3.24 | Monitor | Open Drain or Open Collector | Active Low | 140ms Minimum
0.8V | TPS3703B3080DSERQ1 | 3.24 | Monitor | Open Drain or Open Collector | Active Low | 14ms Minimum
1.2V | TPS3703A4120DSERQ1 | 3.24 | Monitor | Open Drain or Open Collector | Active Low | 140ms Minimum
1.2V | TPS3703A7120DSERQ1 | 3.24 | Simple Reset/Power-On Reset | Open Drain or Open Collector | Active Low | -
0.9V | TPS3703A5090DSERQ1 | 3.24 | Simple Reset/Power-On Reset | Open Drain or Open Collector | Active Low | -
1.1V | TPS3703A7110DSERQ1 | 3.24 | Simple Reset/Power-On Reset | Open Drain or Open Collector | Active Low | -
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

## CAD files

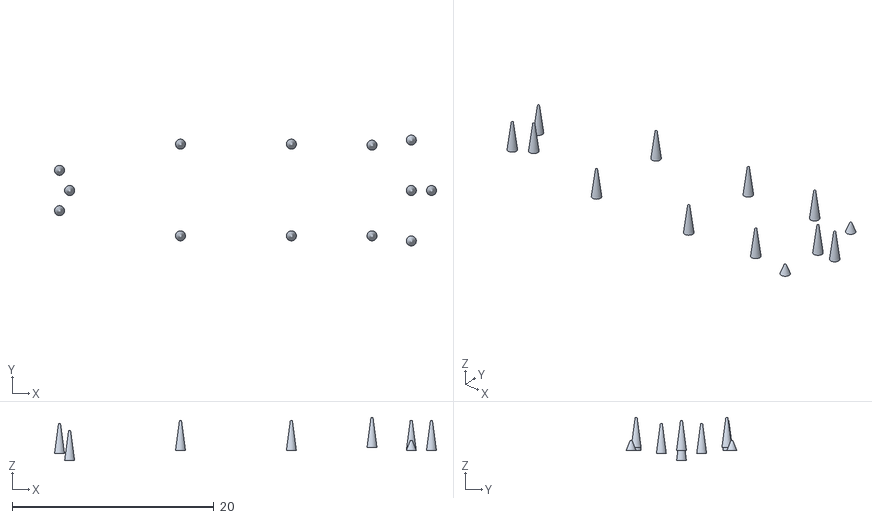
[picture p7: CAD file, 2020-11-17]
P08_01_00 Thingverse CAD/cute_caterpillar/P08_01_00 Modifications/Supports.stl
37.9 x 11.0 x 4.30

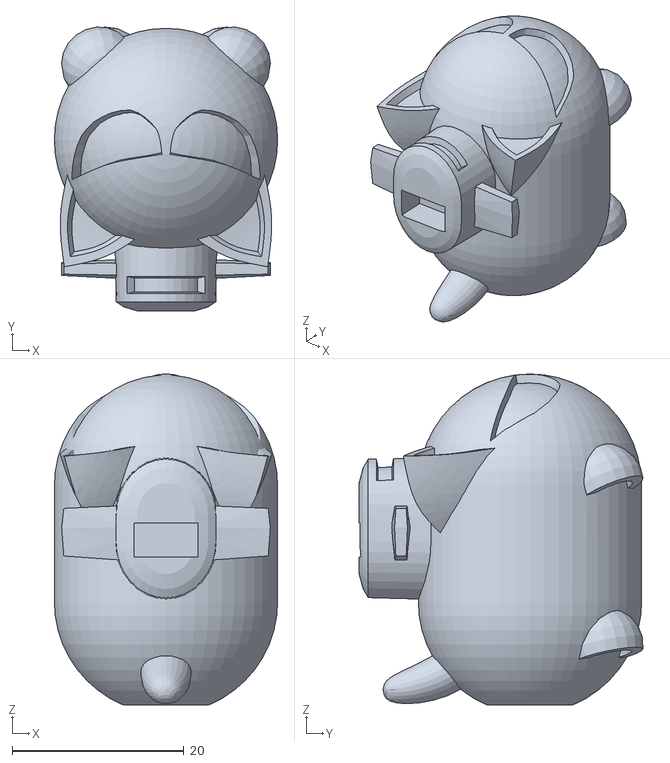
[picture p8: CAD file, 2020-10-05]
P08_01_00 Thingverse CAD/Neko_Submarine/files/NekoSub_body.stl
26.0 x 33.0 x 38.5

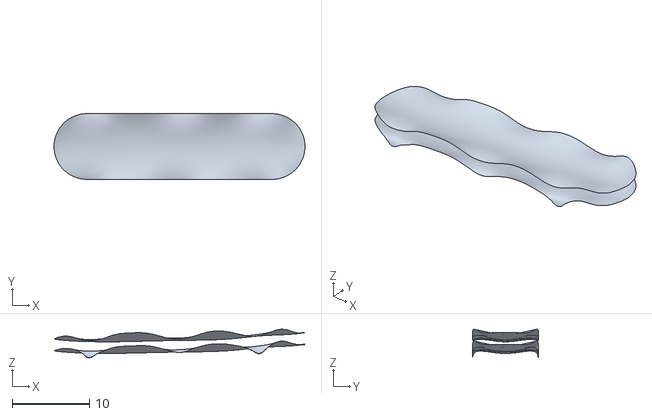
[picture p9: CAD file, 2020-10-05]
P08_01_00 Thingverse CAD/cute_caterpillar/P08_01_00 Modifications/P08_01_00 Plug.stl
32.5 x 8.50 x 3.71

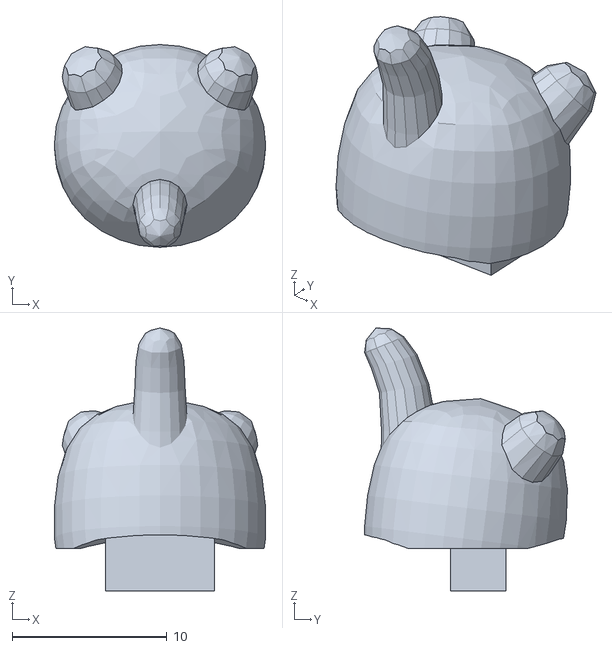
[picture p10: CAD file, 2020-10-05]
P08_01_00 Thingverse CAD/Neko_Submarine/files/NekoSub_crew-Michael.stl
13.7 x 13.1 x 17.0

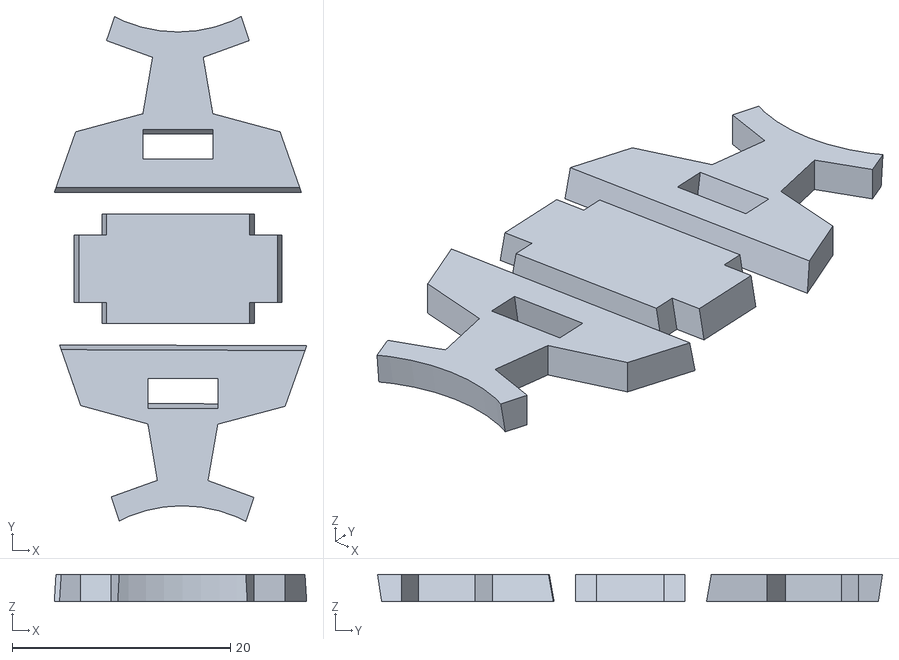
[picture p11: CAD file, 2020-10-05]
P08_01_00 Thingverse CAD/Neko_Submarine/files/NekoSub_stand.stl
23.1 x 46.3 x 2.51

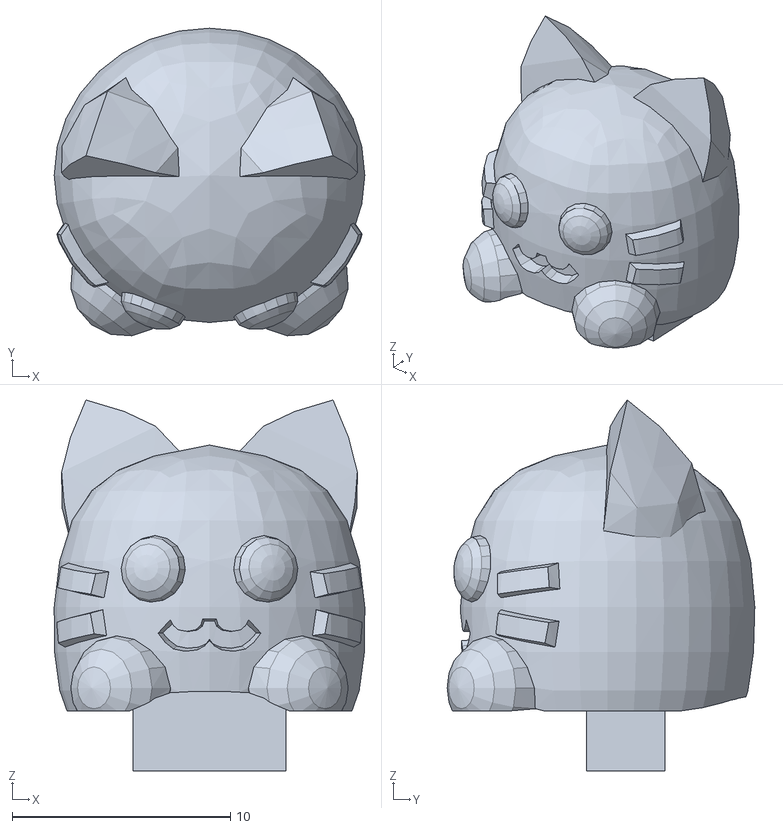
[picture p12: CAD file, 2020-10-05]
P08_01_00 Thingverse CAD/Neko_Submarine/files/NekoSub_crew-Tama.stl
14.2 x 14.1 x 17.0

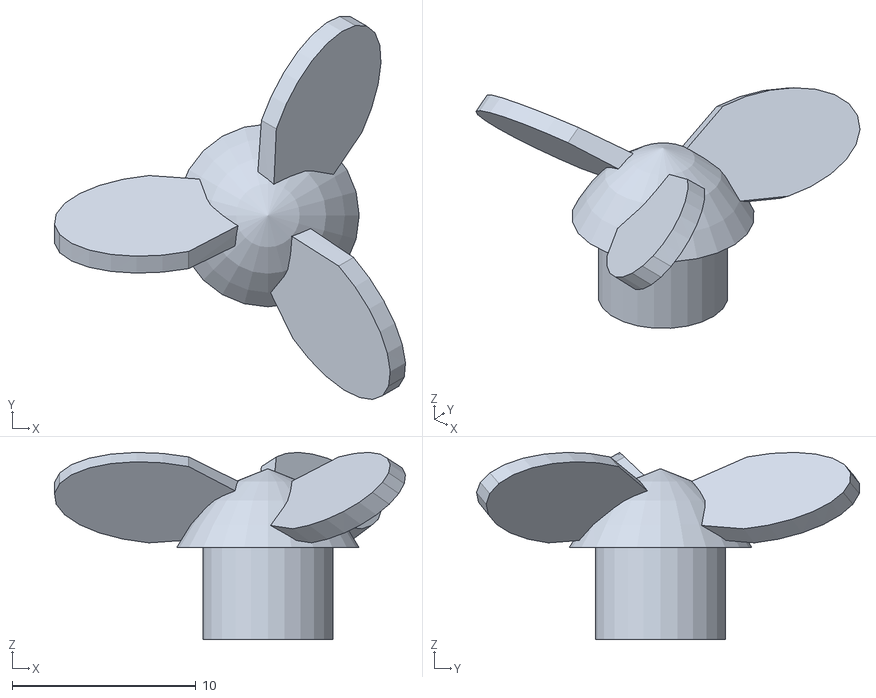
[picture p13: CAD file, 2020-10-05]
P08_01_00 Thingverse CAD/Neko_Submarine/files/NekoSub_screw.stl
19.1 x 20.8 x 10.2

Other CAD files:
P08_01_00 Thingverse CAD/Neko_Submarine/files/NekoSub_crew-Kotetsu.stl
P08_01_00 Thingverse CAD/Neko_Submarine/files/NekoSub_crew-Tom.stl

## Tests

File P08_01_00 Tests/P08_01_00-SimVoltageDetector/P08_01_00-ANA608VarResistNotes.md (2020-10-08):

2020-10-08 
 * Test did not work as expected 
 * Changing the input voltage at CE had no effect
 * I will try using a battery instead of capacitor

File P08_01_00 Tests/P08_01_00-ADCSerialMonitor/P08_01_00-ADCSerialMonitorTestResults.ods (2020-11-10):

Volts | ADC Value
1.72 | 641
1.8 | 614
1.9 | 580
2 | 550
2.1 | 524
2.2 | 500
2.3 | 474
2.41 | 455
2.53 | 436
2.61 | 421
2.73 | 402
2.82 | 389
3.01 | 360
3.12 | 350
3.23 | 336
3.33 | 330
3.42 | 320
3.5 | 310
3.62 | 305
3.71 | 299
3.8 | 294
3.9 | 276
3.91 | 278
3.99 | 274
4.1 | 266
4.19 | 260
4.29 | 253
4.39 | 246
4.49 | 241
4.59 | 234
4.69 | 230
4.8 | 225
4.89 | 220
5 | 215
5.1 | 208
5.2 | 202
5.3 | 194
5.4 | 190
5.5 | 185

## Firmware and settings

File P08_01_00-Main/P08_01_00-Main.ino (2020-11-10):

/*
   P08_01_00-Main
   Project: P08_01_00 Solar HydroBeacon
   Schematic: 
   Description: Read VCC input and control ANA608 on/off sate
  
   Credits
   * Reading ADC
     https://hackaday.io/project/164682-a-cheap-and-dangerous-garden-light-boost-converter/details
   * Software serial tutorial
     https://www.marcelpost.com/wiki/index.php/ATtiny85_ADC
*/

//Variables
byte Red = 0;
byte Green = 1;
byte SensorPwr = 2;
byte RefPin = A2;
byte SoilPin = A3;
int RefVal;
int SoilVal;
/*
#include <SoftwareSerial.h>
#define RX    0   //Pin 3 -> Green
#define TX    1   //Pin 4 -> White
SoftwareSerial Serial(RX, TX);
*/

void setup() {
  pinMode(Green, OUTPUT);
  pinMode(Red, OUTPUT);
  pinMode(SensorPwr, OUTPUT);
  pinMode(RefPin, INPUT);
  pinMode(SoilPin, INPUT);
  delay(2000);
  Cycle();
  //Serial.begin(9600);
}



void loop()
{
  digitalWrite(SensorPwr,HIGH);
  delay(500);
  RefVal = analogRead(RefPin);
  SoilVal = analogRead(SoilPin);
  digitalWrite(SensorPwr,LOW);
  /*
  Serial.print(SoilVal);
  Serial.print(",");
  Serial.println(RefVal);
  delay(2000);
  */
  
  if(SoilVal > RefVal){
    BlinkGreen();
    //Serial.println("Green");
  }
  else{
    BlinkRed();
    //Serial.println("Red");
  }
  delay(10000);
  
}

void BlinkRed(){
  for(int i=0; i<5; i++)
  {
    digitalWrite(Red,HIGH);
    delay(100);
    digitalWrite(Red,LOW);
    delay(200);
    digitalWrite(Red,HIGH);
    delay(100);
    digitalWrite(Red,LOW);
    delay(1000);
  }
}
void BlinkGreen(){
  for(int i=0; i<5; i++)
  {
    digitalWrite(Green,HIGH);
    delay(100);
    digitalWrite(Green,LOW);
    delay(200);
    digitalWrite(Green,HIGH);
    delay(100);
    digitalWrite(Green,LOW);
    delay(1000);
  }
}
void Cycle(){
  for(int i=0; i<5; i++)
  {
    digitalWrite(Green,HIGH);
    delay(100);
    digitalWrite(Green,LOW);
    delay(200);
    digitalWrite(Red,HIGH);
    delay(100);
    digitalWrite(Red,LOW);
    delay(200);
  }
}

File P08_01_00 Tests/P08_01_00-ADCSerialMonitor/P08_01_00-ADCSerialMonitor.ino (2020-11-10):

/*
   P08_01_00-ADCSerialMonitor
   Project: P08_01_00 Solar HydroBeacon
   Schematic: 
   Description: Read VCC from ADC value and post via serial monitor
  
   Credits
   * Reading ADC
     https://hackaday.io/project/164682-a-cheap-and-dangerous-garden-light-boost-converter/details
   * Software serial tutorial
     https://www.marcelpost.com/wiki/index.php/ATtiny85_ADC
*/

//Serial printing on the ATtiny85
#include <SoftwareSerial.h>
#define RX    3   //Pin 3 -> Green
#define TX    4   //Pin 4 -> White
SoftwareSerial Serial(RX, TX);

//Variables
int16_t ADC_Value;

// ADC ISR triggers after conversion.
ISR( ADC_vect )
{
  int16_t v;
  v = ADCL;
  v |= (ADCH << 8);
  ADC_Value = v;
}

// configures ADC for reading battery supply voltage
void ADC_autostart(void)
{
  // see table 17-3, Vcc as Voltage Reference, read Vbg
  ADMUX =
    (0 << ADLAR) |     // 1=left shift result for 8-bit, 0=10-bit
    (0 << REFS2) |     // Sets ref. bit 2
    (0 << REFS1) |     // Sets ref. bit 1
    (0 << REFS0) |     // Sets ref. bit 0
    (1 << MUX3)  |     // MUX bit 3  see table 17-4 for mux sel
    (1 << MUX2)  |     // MUX bit 2
    (0 << MUX1)  |     // MUX bit 1
    (0 << MUX0);       // MUX bit 0

  //ISR on, freerun auto-trigger, 128 prescaler, about 630sps @ 1mHz clock
  ADCSRA =
    (1 << ADIE)  |    //ISR en
    (1 << ADATE) |    //autotrigger
    (1 << ADEN)  |    // Enable ADC
    (1 << ADPS2) |    // prescaler bit 2
    (1 << ADPS1) |    // prescaler bit 1
    (1 << ADPS0);     // prescaler bit 0

  ADCSRB = 0;   //free run

  ADCSRA |= (1 << ADSC);          // start ADC, should trigger ISR
}



void setup() {
  Serial.begin(9600);
  ADC_autostart();  //Start ADC feedback loop
  Serial.println("");
}



void loop()
{
  Serial.println(ADC_Value);
}

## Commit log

2020-10-05 Modify Catapillar CAD
    [DigiKey Voltage Supervisors.xlsx, NekoSub_body.stl, NekoSub_crew-Kotetsu.stl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]
2020-10-08 Testing ANA608
    [P08_01_00-ANA608VarResist.fzz]
2020-10-17 VarResistor tests
    [P08_01_00-ANA608VarResist.fzz]
2020-11-10 main update
    [P08_01_00-Main.fzz]
2020-11-13 Create P08_01_00 BodyWithLDR.stl
2020-11-17 Modify CAD
    [Supports.stl]
